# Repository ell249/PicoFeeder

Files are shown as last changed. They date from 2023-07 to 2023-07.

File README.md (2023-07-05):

# PicoFeeder
RP2040 Pico W with integrated Stepper Driver Board

See https://ell-tech.com/dog-feeder/ running ESPHome 2023.6.4 for more information

Adapted from the Big Easy Driver by Brian Schmalz https://www.schmalzhaus.com/BigEasyDriver/ and adapted by Sparkfun https://github.com/sparkfun/Big_Easy_Driver/tree/V_HW1.6a_FW1.0 

Licenced under https://creativecommons.org/licenses/by-sa/3.0/

Please note the following changes in this Big Easy Driver V1.6E from the original V1.6:
- Buck converter has been incorporated to replace LM317 linear regulator to provide additional power for the RP2040.
- Enable pin now pulled-up by default (instead of down) to start stepper driver disabled. Cut and solder JP15 to enable by default.

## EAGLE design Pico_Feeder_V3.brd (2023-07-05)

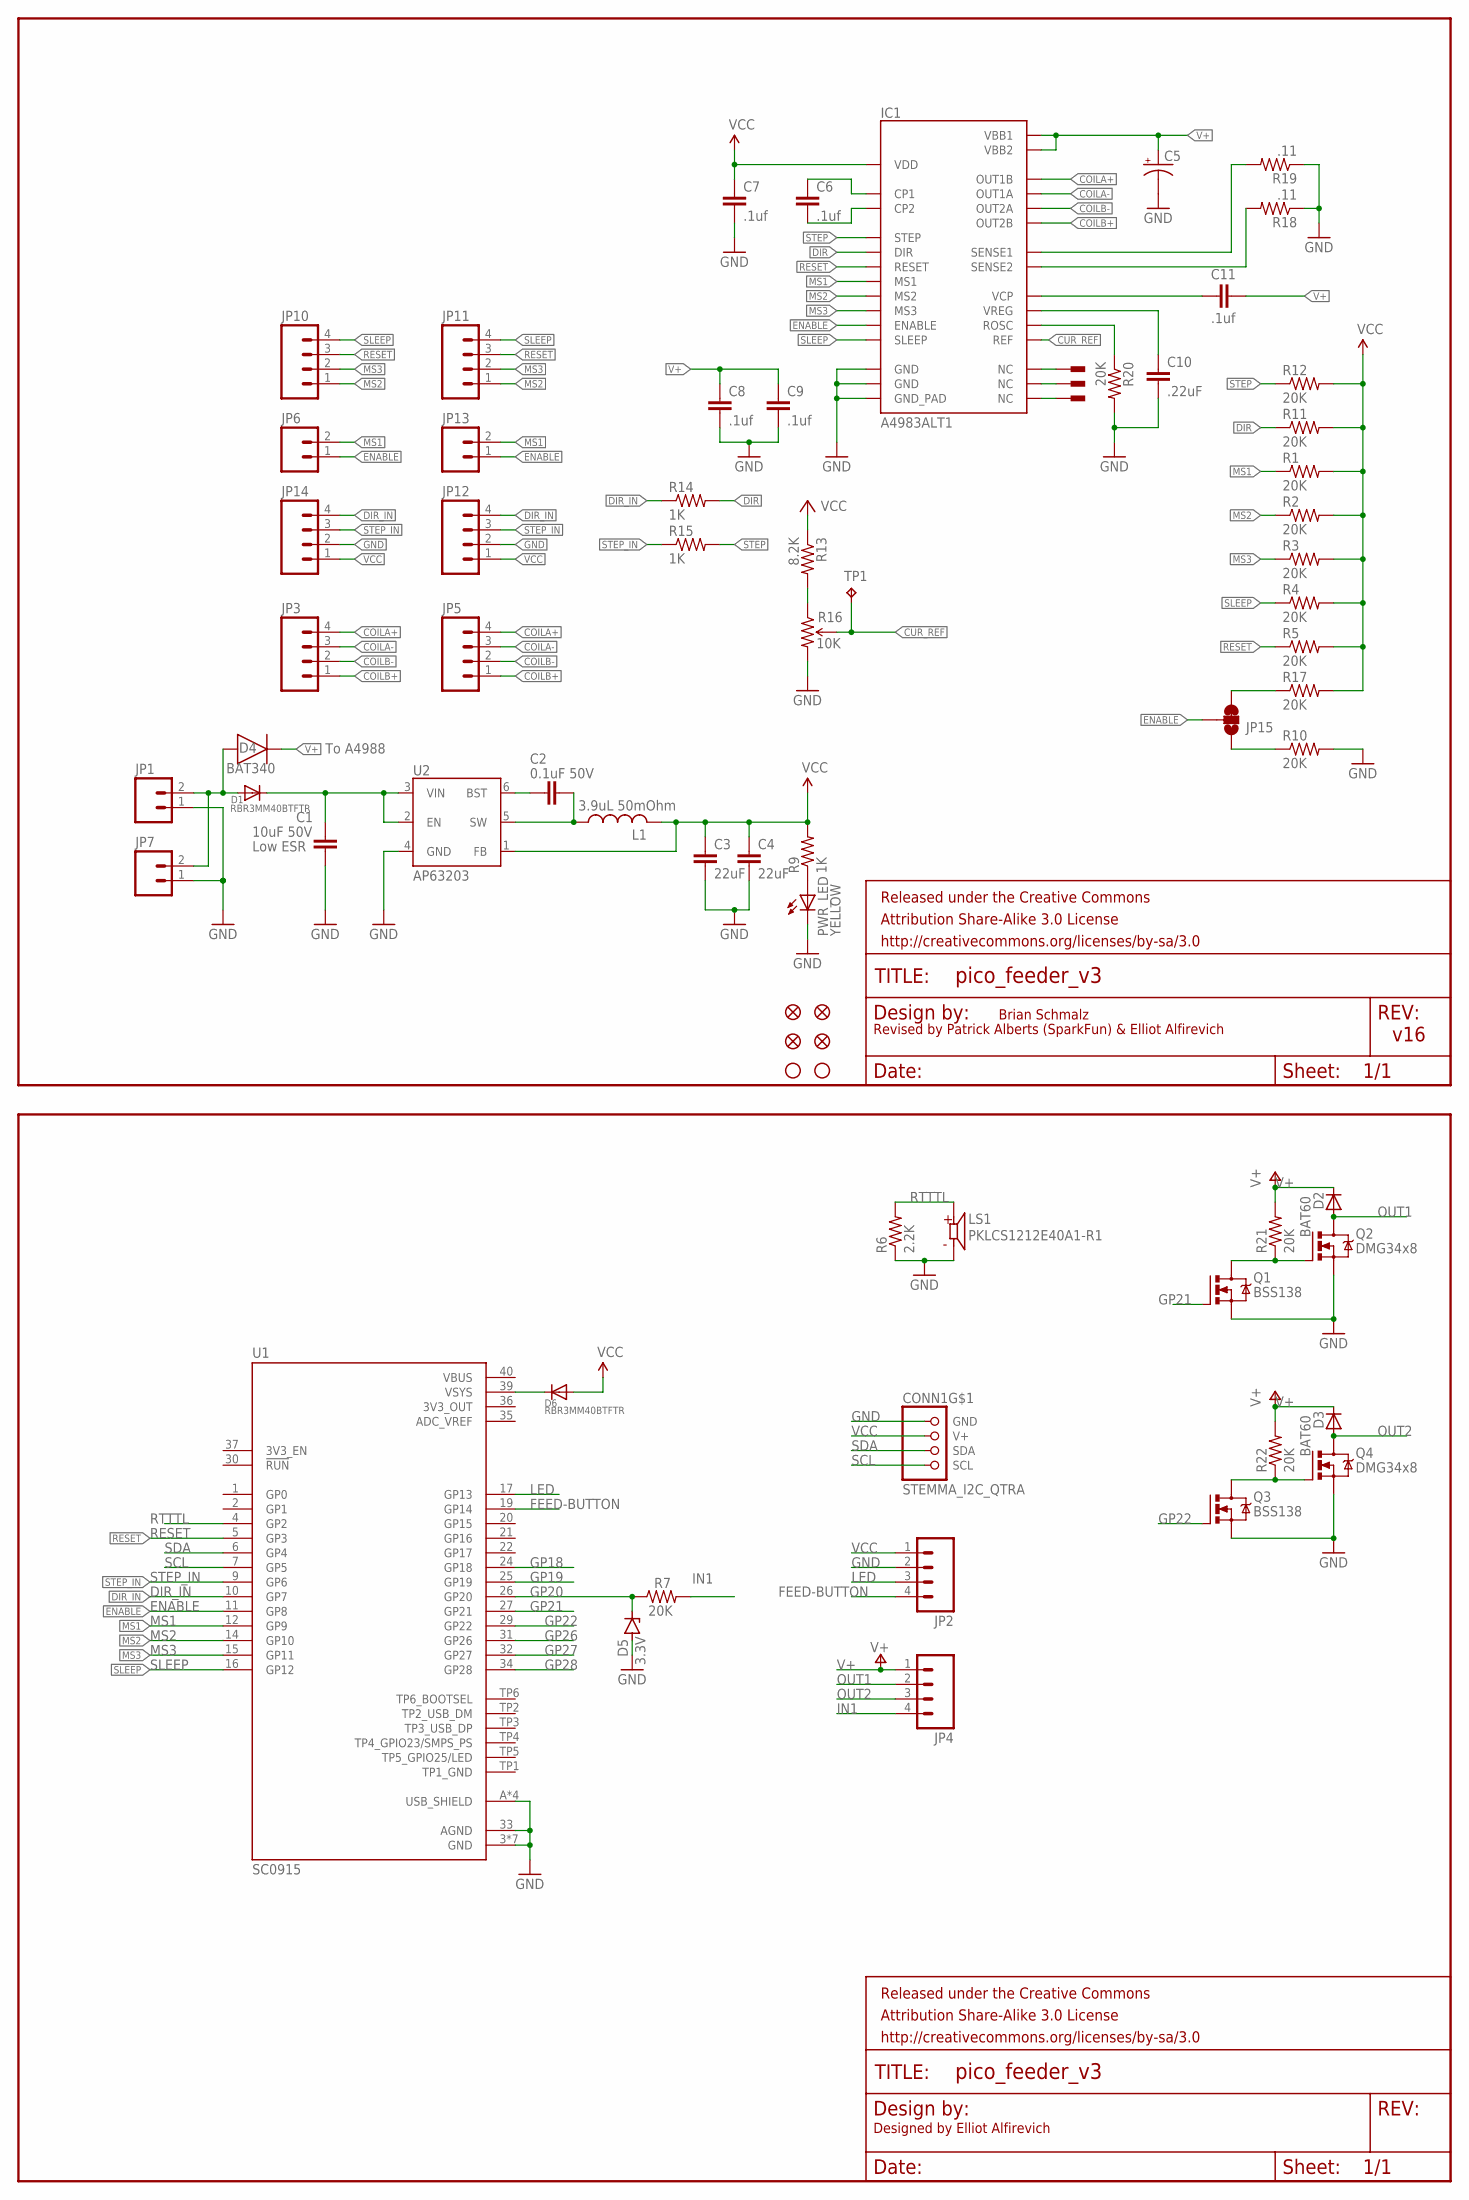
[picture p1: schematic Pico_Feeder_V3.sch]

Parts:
C1: 10uF 50V; CAPC2012X110
C2: 0.1uF 50V; CAPC2012X110
C3, C4: 22uF; 0603-CAP
C5: CPOL-USD; PANASONIC_D
C6, C7, C8, C9, C11: .1uf; 0603-CAP
C10: .22uF; 0603-CAP
CONN1: STEMMA_I2C_QTRA; JST_SH4_RA
D1, D6: RBR3MM40BTFTR; SOD-123FL
D2, D3: BAT60; SOD323-R
D4: BAT340; DIOM5226X290N
D5: 3.3V; SODFL2513X70
FID1, FID2, FID3, FID4: FIDUCIAL1X2; FIDUCIAL-1X2
FRAME1, FRAME2: FRAME-LETTER; CREATIVE_COMMONS
IC1: A4983ALT1; QFN-28-5MM_ALT1
JP1, JP6: M02PTH; 1X02
JP2, JP4, JP5, JP11, JP12: M04SCREW_LOCK; SCREWTERMINAL-3.5MM-4_LOCK
JP3, JP10, JP14: M04PTH; 1X04
JP7, JP13: M023.5MM_LOCK; SCREWTERMINAL-3.5MM-2_LOCK
JP8, JP9: STAND-OFF
JP15: JUMPER-SMT_3_1-NC_TRACE_SILK; SMT-JUMPER_3_1-NC_TRACE_SILK
L1: 3.9uL 50mOhm; LQH55; LCSC C5289415
LS1: PKLCS1212E40A1-R1; SPKR_PKLCS1212E40A1-R1
PWR_LED: YELLOW; LED-0603
Q1, Q3: BSS138; SOT23
Q2, Q4: DMG34x8; SOT23
R1, R2, R3, R4, R5, R7, R10, R11, R12, R17, R20, R21, R22: 20K; 0603-RES
R6: 2.2K; 0603-RES
R9, R14, R15: 1K; 0603-RES
R13: 8.2K; 0603-RES
R16: 10K; TRIMPOT-3MM-2
R18, R19: .11; R2010
TP1: TPPAD1-13; P1-13
U1: SC0915; MODULE_SC0915
U2: AP63203; SOT23-6
U$3, U$4, U$5: PAD; PAD-0.008

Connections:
3V3_OUT: U1.36 (3V3_OUT)
ADC_VREF: U1.35 (ADC_VREF)
COILA+: IC1.P$21 (OUT1B), JP3.4, JP5.4
COILA-: IC1.P$24 (OUT1A), JP3.3, JP5.3
COILB+: IC1.P$1 (OUT2B), JP3.1, JP5.1
COILB-: IC1.P$26 (OUT2A), JP3.2, JP5.2
CUR_REF: IC1.P$17 (REF), R16.2 (WIPER), TP1.TP
DIR: IC1.P$19 (DIR), R11.1, R14.2
DIR_IN: JP12.4, JP14.4, R14.1, U1.10 (GP7)
ENABLE: IC1.P$2 (ENABLE), JP6.1, JP13.1, JP15.2, U1.11 (GP8)
FEED-BUTTON: JP2.4, U1.19 (GP14)
GND: C1.2, C3.2, C4.2, C5.-, C7.2, C8.2, C9.2, C10.2, CONN1.1 (GND), D5.2 (A), IC1.P$3 (GND), IC1.P$18 (GND), IC1.P$29 (GND_PAD), JP1.1, JP2.2, JP7.1, JP12.2, JP14.2, LS1.N, PWR_LED.C, Q1.2 (S), Q2.2 (S), Q3.2 (S), Q4.2 (S), R6.1, R10.2, R16.3 (CW), R18.1, R19.1, R20.2, U1.3 (GND), U1.8 (GND), U1.13 (GND), U1.18 (GND), U1.23 (GND), U1.28 (GND), U1.33 (AGND), U1.38 (GND), U1.A (USB_SHIELD), U1.B (USB_SHIELD), U1.C (USB_SHIELD), U1.D (USB_SHIELD), U2.4 (GND)
GP18: U1.24 (GP18)
GP19: U1.25 (GP19)
GP20: D5.1 (C), R7.1, U1.26 (GP20)
GP21: Q1.1 (G), U1.27 (GP21)
GP22: Q3.1 (G), U1.29 (GP22)
GP26: U1.31 (GP26)
GP27: U1.32 (GP27)
GP28: U1.34 (GP28)
IN1: JP4.4, R7.2
LED: JP2.3, U1.17 (GP13)
MS1: IC1.P$9 (MS1), JP6.2, JP13.2, R1.1, U1.12 (GP9)
MS2: IC1.P$10 (MS2), JP10.1, JP11.1, R2.1, U1.14 (GP10)
MS3: IC1.P$11 (MS3), JP10.2, JP11.2, R3.1, U1.15 (GP11)
unnamed: C2.1, U2.6 (BST)
unnamed: PWR_LED.A, R9.1
unnamed: R13.2, R16.1 (CCW)
unnamed: C2.2, L1.1, U2.5 (SW)
unnamed: IC1.P$7 (NC), U$3.P$1
unnamed: C1.1, D1.C, U2.2 (EN), U2.3 (VIN)
unnamed: IC1.P$20 (NC), U$4.P$1
unnamed: C6.1, IC1.P$4 (CP1)
unnamed: C6.2, IC1.P$5 (CP2)
unnamed: IC1.P$25 (NC), U$5.P$1
unnamed: Q1.3 (D), Q2.1 (G), R21.1
unnamed: D1.A, D4.2 (A), JP1.2, JP7.2
unnamed: D6.C, U1.39 (VSYS)
unnamed: Q3.3 (D), Q4.1 (G), R22.1
unnamed: JP15.3, R17.1
unnamed: JP15.1, R10.1
unnamed: IC1.P$13 (ROSC), R20.1
unnamed: C10.1, IC1.P$8 (VREG)
unnamed: C11.1, IC1.P$6 (VCP)
unnamed: IC1.P$27 (SENSE2), R18.2
unnamed: IC1.P$23 (SENSE1), R19.2
OUT1: D2.A, JP4.2, Q2.3 (D)
OUT2: D3.A, JP4.3, Q4.3 (D)
RESET: IC1.P$12 (RESET), JP10.3, JP11.3, R5.1, U1.5 (GP3)
RTTTL: LS1.P, R6.2, U1.4 (GP2)
SCL: CONN1.4 (SCL), U1.7 (GP5)
SDA: CONN1.3 (SDA), U1.6 (GP4)
SLEEP: IC1.P$14 (SLEEP), JP10.4, JP11.4, R4.1, U1.16 (GP12)
STEP: IC1.P$16 (STEP), R12.1, R15.2
STEP_IN: JP12.3, JP14.3, R15.1, U1.9 (GP6)
TP1_GND: U1.TP1 (TP1_GND)
V+: C5.+, C8.1, C9.1, C11.2, D2.C, D3.C, D4.1 (C), IC1.P$22 (VBB1), IC1.P$28 (VBB2), JP4.1, R21.2, R22.2
VBUS: U1.40 (VBUS)
VCC: C3.1, C4.1, C7.1, CONN1.2 (V+), D6.A, IC1.P$15 (VDD), JP2.1, JP12.1, JP14.1, L1.2, R1.2, R2.2, R3.2, R4.2, R5.2, R9.2, R11.2, R12.2, R13.1, R17.2, U2.1 (FB)

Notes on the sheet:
Brian Schmalz
v16
Revised by Patrick Alberts (SparkFun) & Elliot Alfirevich
Designed by Elliot Alfirevich
Low ESR
To A4988

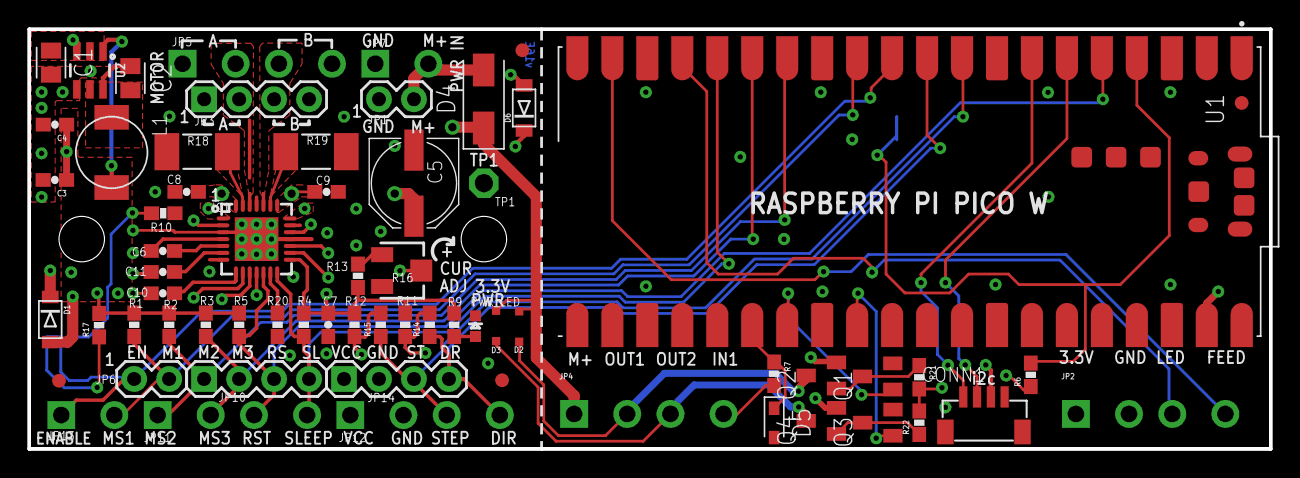
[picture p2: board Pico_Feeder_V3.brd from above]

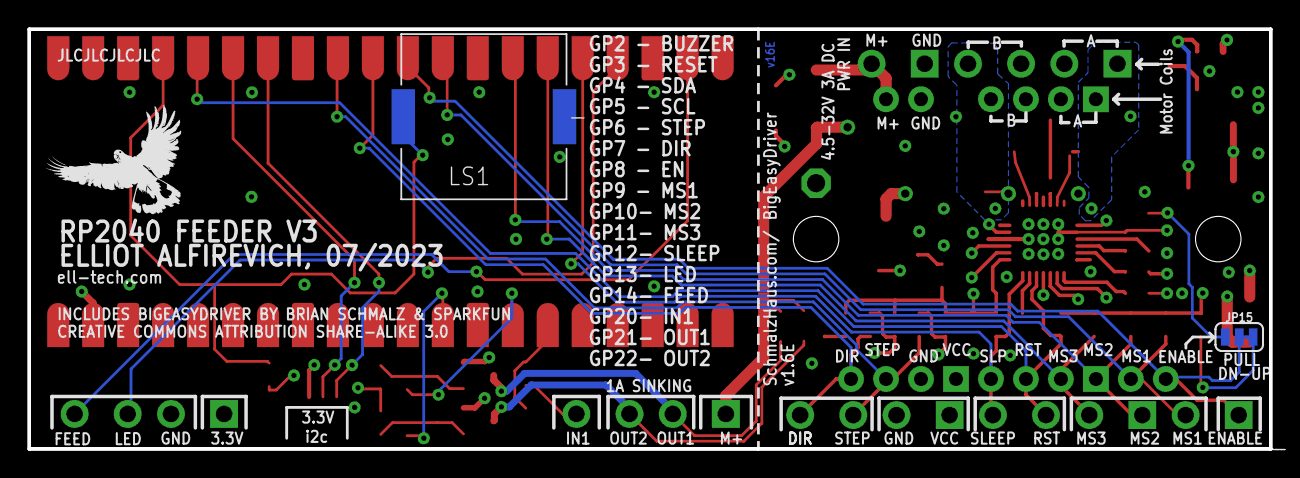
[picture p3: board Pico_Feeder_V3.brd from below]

Board: 4 copper layers, 90.2 x 30.5 mm, 74 parts (2 on the bottom side), 50 nets.

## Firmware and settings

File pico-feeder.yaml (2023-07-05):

esphome:  # running 2023.6.4
  name: pico-feeder
  friendly_name: pico-feeder
  on_boot:
    - output.turn_on: sleepi
    - output.turn_on: reseti
    - output.turn_on: enable
    - output.turn_off: ms1
    - output.turn_off: ms2
    - output.turn_off: ms3
    - rtttl.play: 'MissionImp:d=16,o=6,b=95:32d,32d#,32d,32d#,32d,32d#,32d,32d#,32d,32d,32d#,32e,32f,32f#'

rp2040:
  board: rpipicow
  framework:
    # Required until https://github.com/platformio/platform-raspberrypi/pull/36 is merged
    platform_version: https://github.com/maxgerhardt/platform-raspberrypi.git

# Enable logging
logger:

# Enable Home Assistant API
api:
  encryption:
    key: !secret api_key

ota:
  password: !secret ota_password

wifi:
  ssid: !secret wifi_ssid
  password: !secret wifi_password

  # Enable fallback hotspot in case wifi connection fails
  ap:
    ssid: "pico-feeder"
    password: !secret ap_password

output:
  - platform: rp2040_pwm
    pin: 2
    id: rtttl_out
  - platform: gpio
    pin: 8
    id: enable
  - platform: gpio
    pin: 9
    id: ms1
  - platform: gpio
    pin: 10
    id: ms2
  - platform: gpio
    pin: 11
    id: ms3
  - platform: gpio
    pin: 12
    id: sleepi
  - platform: gpio
    pin: 3
    id: reseti

rtttl:
  output: rtttl_out
  
globals:
  - id: Feed_Amount
    type: float
    restore_value: true
    initial_value: '600.0' 

i2c:
  sda: 4
  scl: 5
  scan: true
  id: bus_a

sensor:
  - platform: vl53l0x
    name: "Food Level"
    id: level1
    address: 0x29
    timeout: 200us
    update_interval: 1min
    unit_of_measurement: "%"
    filters:
      - calibrate_linear:
          # Map 220 (from sensor) to 0% (true value) 
          # full is 25 to 100% (true value) 
          - 0.220 -> 0
          - 0.025 -> 100
  - platform: uptime
    name: Uptime Sensor


stepper:
  - platform: a4988
    id: feed_stepper
    step_pin: 6
    dir_pin: 7
    max_speed: 200 steps/s
    sleep_pin: 
      number: 8
      inverted: True
    acceleration: inf
    deceleration: inf
    
button:
  - platform: template
    name: "Feed Now"
    id: Feed_Now
    icon: mdi:radiobox-marked
    on_press:
      then:
        - logger.log:
            format: "Feeding now amount %f steps"
            args: [ 'id(Feed_Amount)']
        - switch.turn_off:
            id: Hungry_Dog
        - stepper.report_position:
            id: feed_stepper
            position: 0
        - stepper.set_target:
            id: feed_stepper
            target: !lambda 'return int(id(Feed_Amount));'
            # target: 600
        - rtttl.play: 'MissionImp:d=16,o=6,b=95:32d,32d#,32d,32d#,32d,32d#,32d,32d#,32d,32d,32d#,32e,32f'

number:
  - platform: template
    icon: mdi:food-hot-dog
    id: Feed_Amount_Setting
    name: "Feed Amount Setting"
    min_value: 100
    max_value: 1800
    initial_value: 600.0
    step: 1
    set_action:
      then:
       - lambda: id(Feed_Amount) = x;
       - logger.log:
          format: "New feeding amount is %f steps"
          args: [ 'id(Feed_Amount)']
       
switch:
  - platform: gpio
    pin: 13
    name: "Hungry Dog Light"
    id: Hungry_Dog
    icon: mdi:dog
    restore_mode: RESTORE_DEFAULT_ON

binary_sensor:
  - platform: gpio
    pin:
      number: 14
      mode:
        input: true
        pullup: true
      inverted: true
    name: "Feed Button"
    on_press:
      then:
        - button.press: Feed_Now

    

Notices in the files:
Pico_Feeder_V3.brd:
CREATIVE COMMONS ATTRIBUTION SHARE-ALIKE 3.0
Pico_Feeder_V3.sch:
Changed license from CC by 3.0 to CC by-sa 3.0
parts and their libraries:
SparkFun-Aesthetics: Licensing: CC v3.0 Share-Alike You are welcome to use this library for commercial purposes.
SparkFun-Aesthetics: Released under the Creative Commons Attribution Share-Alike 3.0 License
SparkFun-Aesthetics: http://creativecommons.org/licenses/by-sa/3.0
